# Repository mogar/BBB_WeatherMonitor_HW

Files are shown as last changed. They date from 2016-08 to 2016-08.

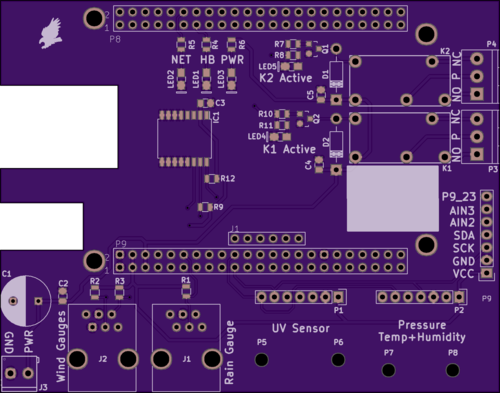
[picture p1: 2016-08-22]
WeatherStationV2_files/WeatherStationV2_front.png

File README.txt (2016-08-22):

These are the hardware design files for a BBB Cape that monitors weather conditions.

See also this repo for example code:

These hardware files were created with KiCAD. You may need the KiCAD libraries available here: https://github.com/mogar/KiCAD_libs When opening these projects in KiCAD, you may need to change the path to the libraries from the above link. This can be done in preferences->libraries in both the schematic editor and the layout editor. Make sure the libraries noted there point to wherever you put the above KiCAD_libs repo.

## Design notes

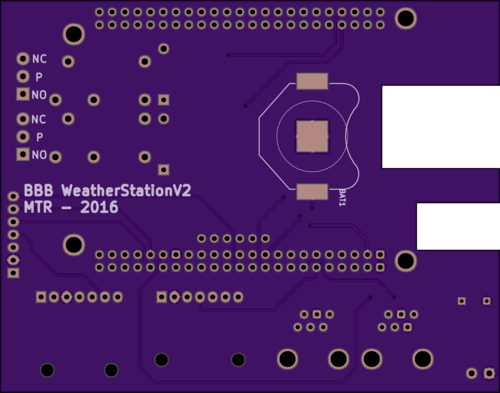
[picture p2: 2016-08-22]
WeatherStationV2_files/WeatherStationV2_back.png

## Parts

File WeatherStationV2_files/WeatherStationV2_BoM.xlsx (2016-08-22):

Id | Designator | Package | Quantity | Order Qty | Designation | Supplier | Ref | Unit Cost | Ext Cost
1 | K2,K1 | RELAY-TE-1FORMC | 2 | 32 | PB890-ND | DigiKey | PB890-ND | 1.87 | 3.74
2 | R2,R3 | R_0805 | 2 | 32 | 10k | DigiKey | RMCF0805JT10K0CT-ND | 0.0088 | 0.0176
3 | R4,R5,R6,R7,R8,R10,R11 | R_0805 | 7 | 112 | 1k | DigiKey | 311-1.0KARCT-ND | 0.0073 | 0.0511
4 | IC1 | SOIC-16_7.5x10.3mm_Pitch1.27mm | 1 | 16 | DS3231/SO | DigiKey | DS3231S#T&RCT-ND | 8.186 | 8.186
5 | R1,R9,R12 | R_0805 | 3 | 48 | 2.2k | DigiKey | RMCF0805JT2K20CT-ND | 0.0088 | 0.0264
6 | BAT1 | BATTCON_20MM | 1 | 16 | ~ | DigiKey | BAT-HLD-001-ND | 0.2568 | 0.2568
7 | P1,P2 | Pin_Header_Straight_1x07 | 2 | 32 | CONN_01X07 | DigiKey | S7005-ND | 0.605 | 1.21
8 | P3,P4 | TerminalBlock_Pheonix_PT-3.5mm_3pol | 2 | 32 | CONN_01X03 | DigiKey | 277-1722-ND | 0.587 | 1.174
9 | C1 | C_Radial_D10_L16_P5 | 1 | 16 | 470u | DigiKey | 493-5898-1-ND | 0.227 | 0.227
10 | C3,C4,C5 | C_0805 | 3 | 48 | 1u | DigiKey | 311-1365-1-ND | 0.0318 | 0.0954
11 | D1,D2 | Diode_DO-41_SOD81_Horizontal_RM10 | 1 | 16 | 1N4004 | DigiKey | 1N4004DICT-ND | 0.115 | 0.115
12 | J3 | SparkFun-SCREWTERMINAL-3.5MM-2 | 1 | 16 | 1X2-3.5MM | DigiKey | 277-1721-ND | 0.391 | 0.391
13 | Q1,Q2 | SOT-23 | 2 | 32 | MMBT3904 | DigiKey | MMBT3904FSCT-ND | 0.142 | 0.284
14 | C2 | C_0805 | 1 | 16 | 10u | DigiKey | 490-1718-1-ND | 0.0356 | 0.0356
15 | LED1,LED2,LED3,LED4,LED5 | 0805P-HandSoldering | 5 | 80 | LED | DigiKey | 67-1557-1-ND | 0.328 | 1.64
16 | J1,J2 | RJ12-A-2014-1-4-R | 2 | 32 | A-2014-1-4-R | DigiKey | AE10391-ND | 0.615 | 1.23
17 | PCB1 | BEAGLEBONE_BLACK | 1 | 16 | E14_BEAGLEBONEBLACK_REVA_BEAGLEBONE_BLACK | AdaFruit | BBB revC | 55 | 55
18 | PCB2 | Cape | 1 | 16 |  | OSHPark |  | 20 | 20
19 |  | Temp/Press/Humidity | 1 | 16 |  | AdaFruit | bme280 | 19.95 | 19.95
20 |  | UV Sensor | 1 | 16 |  | AdaFruit | si1145 | 9.95 | 9.95
 |  |  |  |  |  |  |  |  | 123.5799

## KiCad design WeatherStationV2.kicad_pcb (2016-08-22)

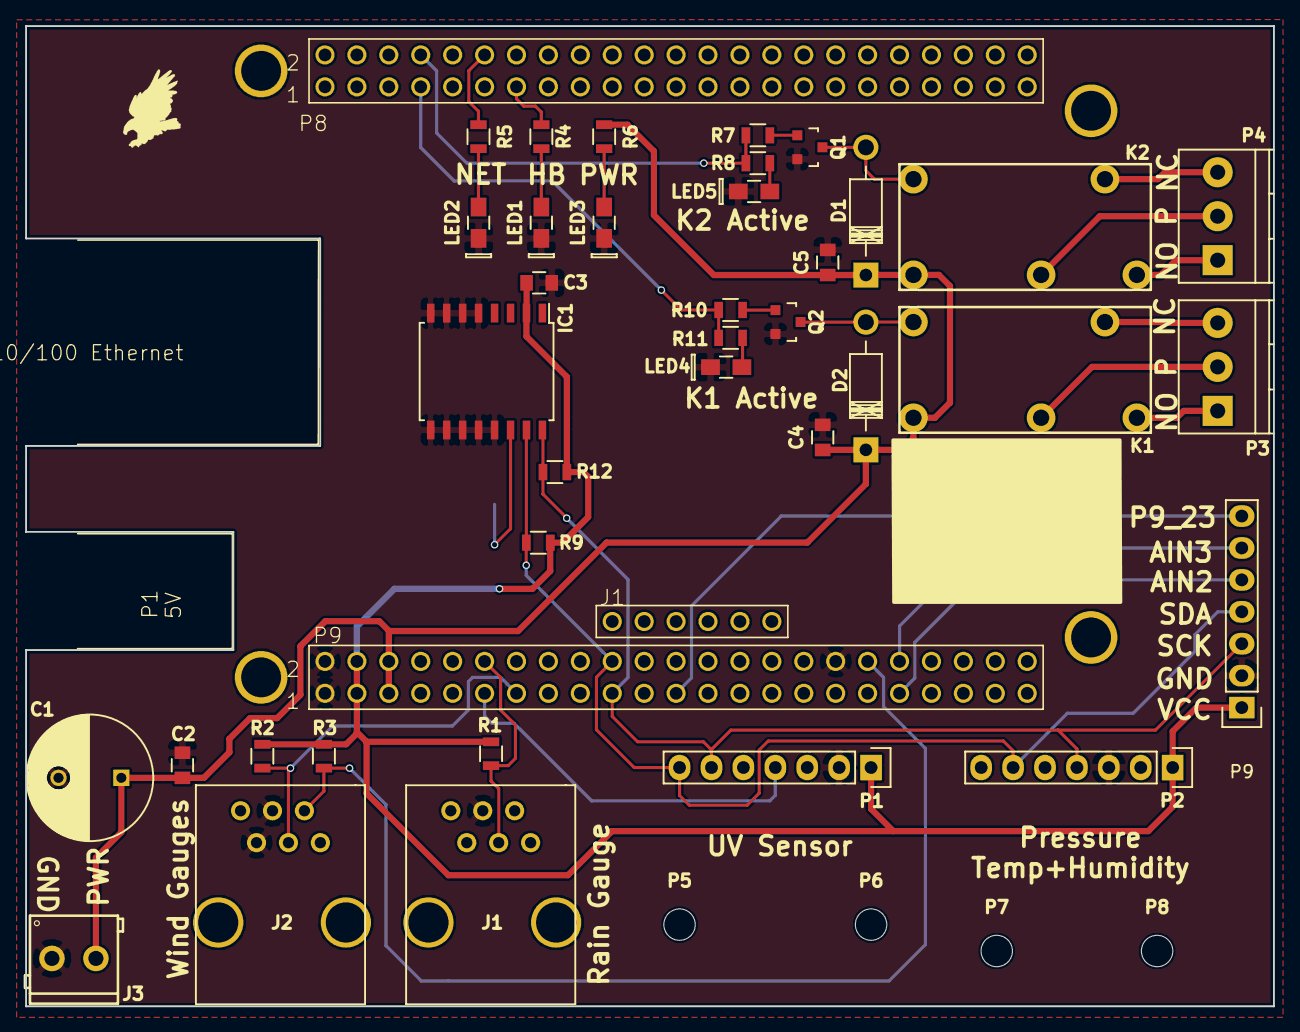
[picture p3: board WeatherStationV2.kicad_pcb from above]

Board: 2 copper layers, 99.3 x 78.0 mm, 43 parts (0 on the bottom side), 32 nets.

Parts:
BAT1: BATTCON_20MM
C1: 470u; C_Radial_D10_L16_P5
C2: 10u; C_0805
C3, C4, C5: 1u; C_0805
D1: 1N4004; Diode_DO-41_SOD81_Horizontal_RM10
D2: 1n4004; Diode_DO-41_SOD81_Horizontal_RM10
IC1: DS3231/SO; SOIC-16_7.5x10.3mm_Pitch1.27mm
J1, J2: A-2014-1-4-R; RJ12-A-2014-1-4-R
J3: 1X2-3.5MM; SparkFun-SCREWTERMINAL-3.5MM-2
K1, K2: PB890-ND; RELAY-TE-1FORMC
LED1, LED2, LED3, LED4, LED5: LED; 0805P-HandSoldering
P1, P2, P9: CONN_01X07; Pin_Header_Straight_1x07
P3, P4: CONN_01X03; TerminalBlock_Pheonix_PT-3.5mm_3pol
P5, P6, P7, P8: CONN_01X01; MountingHole_2.5mm
PCB1: E14_BEAGLEBONEBLACK_REVA_BEAGLEBONE_BLACK; BEAGLEBONE_BLACK
Q1, Q2: MMBT3904; SOT-23
R1, R9, R12: 2.2k; R_0805
R2, R3: 10k; R_0805
R4, R5, R6, R7, R8, R10, R11: 1k; R_0805

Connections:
+3V3: C3.1, IC1.2, P1.1, P2.1, P9.1, PCB1.9_3, PCB1.9_4, R1.2, R2.2, R3.2, R9.2, R12.2
+5V: C1.1, C2.1, C4.1, C5.1, D1.1, D2.1, J3.2, K1.5, K2.5, PCB1.9_5, PCB1.9_6, R6.1
/AIN2: P9.5, PCB1.9_37
/AIN3: P9.6, PCB1.9_38
/HB_LED: PCB1.8_13, R4.1
/I2C_SCK: IC1.16, P1.6, P2.4, P9.3, PCB1.9_19, R12.1
/I2C_SDA: IC1.15, P1.7, P2.6, P9.4, PCB1.9_20, R9.1
/K1_NC: K1.4, P3.3
/K1_NO: K1.3, P3.1
/K1_P: K1.2, P3.2
/K2_NC: K2.4, P4.3
/K2_NO: K2.3, P4.1
/K2_P: K2.2, P4.2
/NET_LED: PCB1.8_12, R5.1
/P9_23: P9.7, PCB1.9_23
/RAIN_SW: J1.4, PCB1.9_12, R1.1
/RELAY1: PCB1.8_7, R10.1, R11.1
/RELAY2: PCB1.8_8, R7.1, R8.1
/UV_Int: P1.4, PCB1.9_11
/WIND_DIR: J2.5, PCB1.9_36, R3.1
/WIND_SP: J2.4, PCB1.9_13, R2.1
GND: BAT1.2, C1.2, C2.2, C3.2, C4.2, C5.2, IC1.5, IC1.6, IC1.7, IC1.8, IC1.9, IC1.10, IC1.11, IC1.12, IC1.13, J1.3, J2.2, J2.3, J3.1, LED1.1, LED2.1, LED3.1, LED4.1, LED5.1, P1.2, P2.3, P9.2, PCB1.9_1, PCB1.9_2, PCB1.9_34, Q1.2, Q2.2
unnamed: BAT1.1, IC1.14
unnamed: D1.2, K2.1, Q1.3
unnamed: D2.2, K1.1, Q2.3
unnamed: LED1.2, R4.2
unnamed: LED2.2, R5.2
unnamed: LED3.2, R6.2
unnamed: LED4.2, R11.2
unnamed: LED5.2, R8.2
unnamed: Q1.1, R7.2
unnamed: Q2.1, R10.2
